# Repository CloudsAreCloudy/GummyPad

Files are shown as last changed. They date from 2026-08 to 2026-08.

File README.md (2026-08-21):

# GummyPad
An ESP32 C3 SuperMini Macropad with 12 Keys, an OLED Display, Rotary Encoder, and RGB LEDs!



## Bill of Materials (BOM)
| Part | Price (USD) | Quantity | Where to find it |
| ---- | ----- | --- | --- |
| M3x4mmx4.2mm Heat Set Brass Inserts | 0.45$ | 10 | [Purchase Here](https://quartzcomponents.com/products/m3-x-4mm-brass-heat-set-threaded-round-insert-nut-10-pcs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) |
| 100nF Capacitors | 0.32$ | 9 | [Purchase Here](https://quartzcomponents.com/products/100nf-0-1uf-50v-capacitor-0805-smd-pack-of-20-piece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) |
| SSD1306 0.96 Inch OLED Display | 1.51$ | 1 | [Purchase Here](https://quartzcomponents.com/products/oled-display-0-96-inch-i2c-interface-4-pin-blue-ssd1306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) |
| 3.7V 2000mAH Li-Po Battery | 2.58$ | 1 | [Purchase Here](https://quartzcomponents.com/products/3-7v-2000mah-li-po-rechargeable-battery-523450?variant=44853322449130) |
| TP4056 Charging Module | 0.17$ | 1 | [Purchase Here](https://quartzcomponents.com/products/tp4056-battery-charging-protection-module-type-c?variant=39545849774264) |
| 1N148 High-speed Diode | 0.38$ | 12 | [Purchase Here](https://quartzcomponents.com/products/1n4148-zener-diode?variant=42817413546218) |
| KY-040 Rotary Encoder | 0.49$ | 1 | [Purchase Here](https://quartzcomponents.com/products/rotary-encoder-module-ky-040?variant=39545890963640) |
| WS2821B 5050 LED Light | 0.94$ | 9 | [Purchase Here](https://probots.co.in/ws2812b-rgb-led-chip-5050-smd-white-addressable-intelligent.html) |
| M3 x 6mm Screws | 0.13$ | 10 | [Purchase Here](https://onlyscrews.in/products/m3-x-6mm-phillips-csk-ss-304-screw-dia-3mm-length-6mm?variant=52107976802617)
| M2.5 x 4mm Screws | 0.03$ | 2 | [Purchase Here](https://onlyscrews.in/products/m2-5-x-4mm-phillips-csk-ss-304-screw-dia-2-5mm-length-4mm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) |
| Keyboard Switches | 1.57$ | 12 | [Purchase Here](https://meckeys.com/shop/accessories/keyboard-accessories/key-switches/regular-switch-3pin/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) |
| ESP32-C3 Super Mini | 2.86$ | 1 | [Purchase Here](https://quartzcomponents.com/products/esp32-c3-super-mini-development-board-with-soldered-headers-hw-466ab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)
| PCB from JLCPCB | 2.18$ | 5 (MOQ) | [Purchase Here](JLCPCB.com) |
| 3D Printing (Self) | 0$ | 1 | NA |
| Shipping | 2.83$ | NA | NA |
| **Total** | 16.44$ | | |

## How can I build it?
 **Required Libraries:**
- ADAFRUIT_SSD1306
- KMK_Firmware

All you need to do is solder the Capacitors, Display, TP4056 Module, Battery, Diodes, Switches, Rotary Encoder, and LEDs onto the PCB, 3D Print the case and use a soldering iron to push the heat set inserts into place (M2.5 screws intentionally dont have heat set inserts), flash the ESP32-C3 Super Mini with CircuitPython, Load the code.py file into the root along with the KMK files and the specified libraries, and you should be good to go!




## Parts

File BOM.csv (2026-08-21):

Part | Price (USD) | Quantity | Where to find it
M3x4mmx4.2mm Heat Set Brass Inserts | 0.45$ | 10 | https://quartzcomponents.com/products/m3-x-4mm-brass-heat-set-threaded-round-insert-nut-10-pcs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
100nF Capacitors | 0.32$ | 9 | https://quartzcomponents.com/products/100nf-0-1uf-50v-capacitor-0805-smd-pack-of-20-piece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
SSD1306 0.96 Inch OLED Display | 1.51$ | 1 | https://quartzcomponents.com/products/oled-display-0-96-inch-i2c-interface-4-pin-blue-ssd1306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
3.7V 2000mAH Li-Po Battery | 2.58$ | 1 | https://quartzcomponents.com/products/3-7v-2000mah-li-po-rechargeable-battery-523450?variant=44853322449130
TP4056 Charging Module | 0.17$ | 1 | https://quartzcomponents.com/products/tp4056-battery-charging-protection-module-type-c?variant=39545849774264
1N148 High-speed Diode | 0.38$ | 12 | https://quartzcomponents.com/products/1n4148-zener-diode?variant=42817413546218
KY-040 Rotary Encoder | 0.49$ | 1 | https://quartzcomponents.com/products/rotary-encoder-module-ky-040?variant=39545890963640
WS2821B 5050 LED Light | 0.94$ | 9 | https://probots.co.in/ws2812b-rgb-led-chip-5050-smd-white-addressable-intelligent.html
M3 x 6mm Screws | 0.13$ | 10 | https://onlyscrews.in/products/m3-x-6mm-phillips-csk-ss-304-screw-dia-3mm-length-6mm?variant=52107976802617
M2.5 x 4mm Screws | 0.03$ | 2 | https://onlyscrews.in/products/m2-5-x-4mm-phillips-csk-ss-304-screw-dia-2-5mm-length-4mm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
Keyboard Switches | 1.57$ | 12 | https://meckeys.com/shop/accessories/keyboard-accessories/key-switches/regular-switch-3pin/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
ESP32-C3 Super Mini | 2.86$ | 1 | https://quartzcomponents.com/products/esp32-c3-super-mini-development-board-with-soldered-headers-hw-466ab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
PCB from JLCPCB | 2.18$ | 5 (MOQ) | jlcpcb.com
3D Printing (Self) | 0$ | 1 | NA
Shipping | 2.83$ | NA | NA
Total | 16.44$

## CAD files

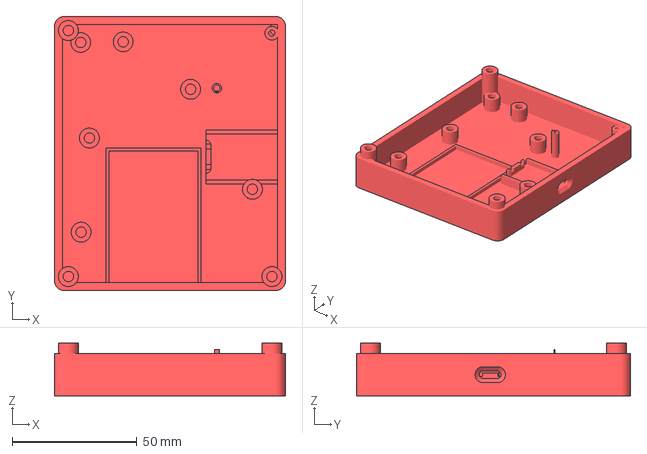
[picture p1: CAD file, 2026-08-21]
CAD/Case_Bottom.3mf
92.6 x 109.7 x 21.2 mm

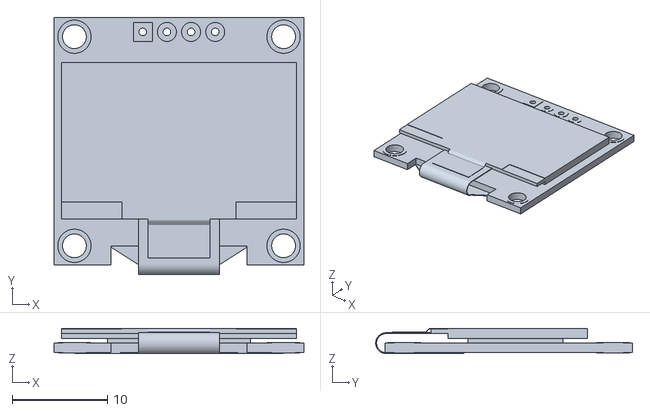
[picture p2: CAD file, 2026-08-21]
CAD/Components/Display_OLED_0.96_128x64.stl
26.3 x 27.0 x 2.65

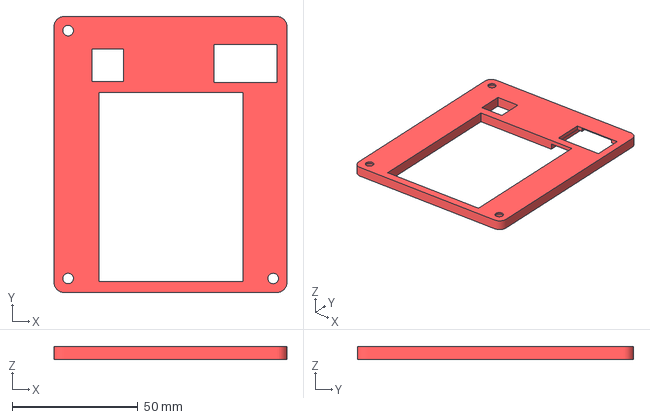
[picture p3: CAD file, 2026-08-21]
CAD/Case_Top.3mf
92.6 x 109.7 x 5.00 mm

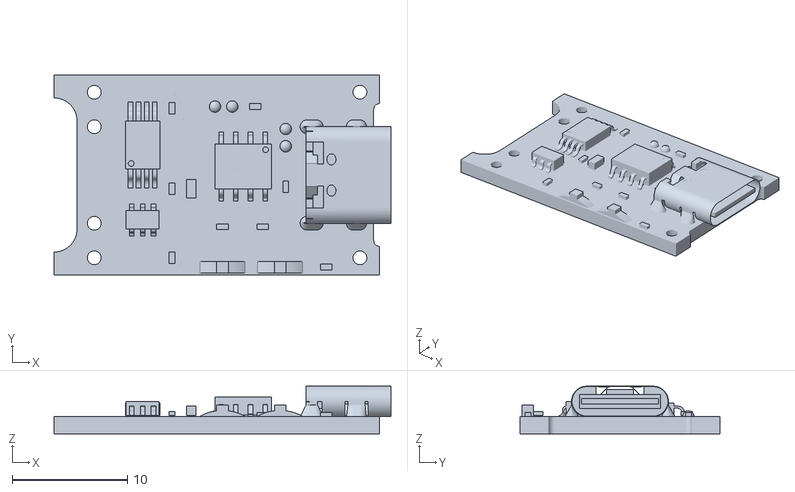
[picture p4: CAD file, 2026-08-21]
CAD/Components/TP4056_Charging_Module_Type_C.stl
29.3 x 17.4 x 4.14

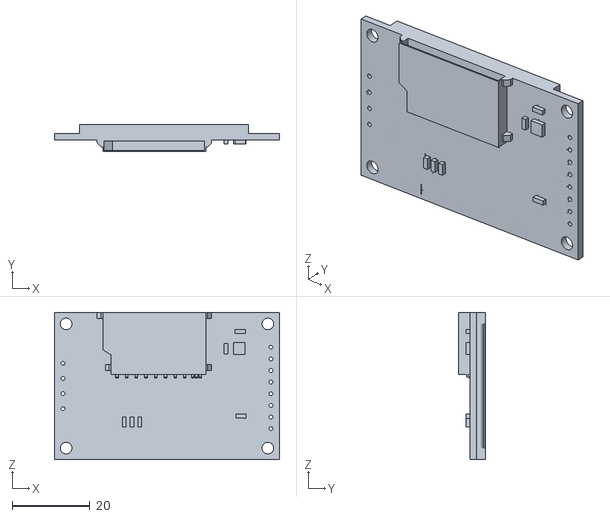
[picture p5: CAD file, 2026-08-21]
CAD/Components/LCD_TFT_1.8_SPI_ST7735.step.stl
58.0 x 7.00 x 38.0

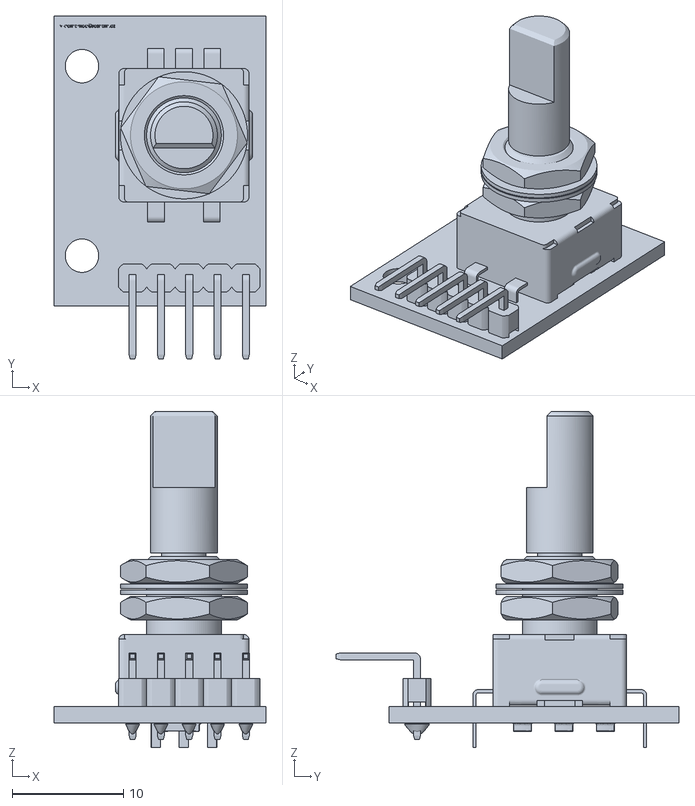
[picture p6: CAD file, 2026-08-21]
CAD/Components/KY-040.stl
19.0 x 30.8 x 30.2

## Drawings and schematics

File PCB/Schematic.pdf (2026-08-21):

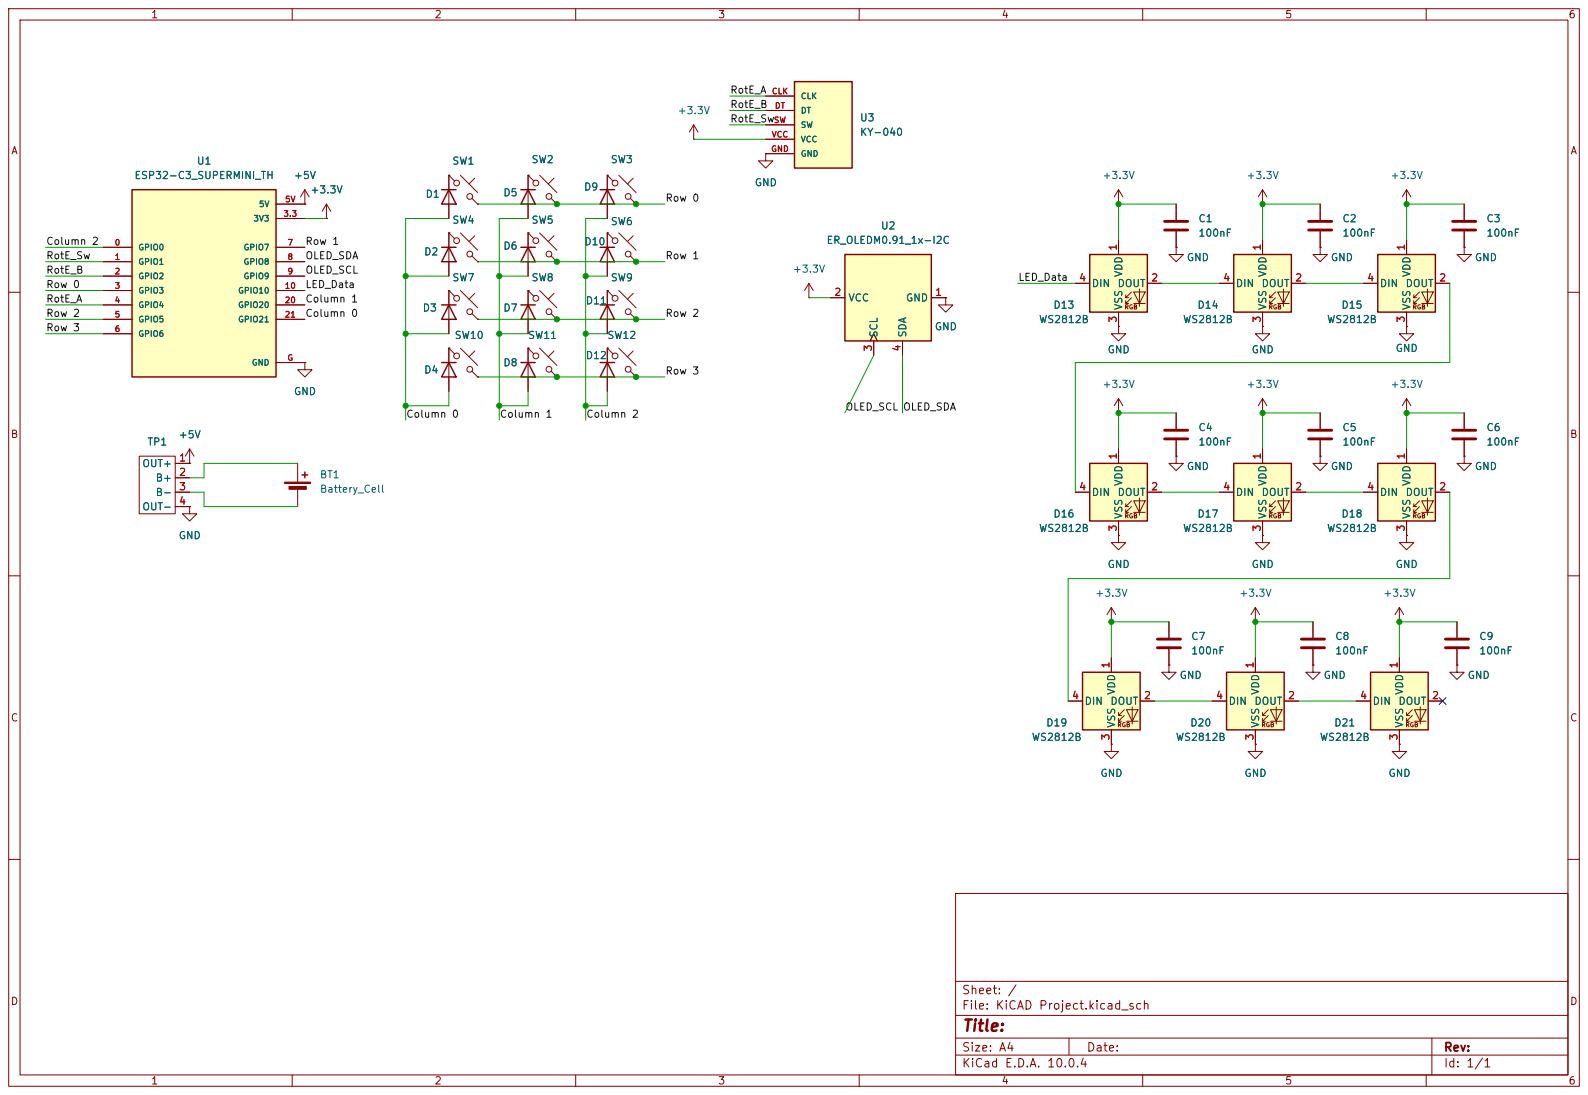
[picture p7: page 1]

LED_Data OLED_SDA OLED_SCL Column 0 Row 1 Row 2 Row 3 RotE_A RotE_B
Column 1 RotE_Sw

Size: A4 | Rev:
KiCad E.D.A. 10.0.4 | Id: 1/1

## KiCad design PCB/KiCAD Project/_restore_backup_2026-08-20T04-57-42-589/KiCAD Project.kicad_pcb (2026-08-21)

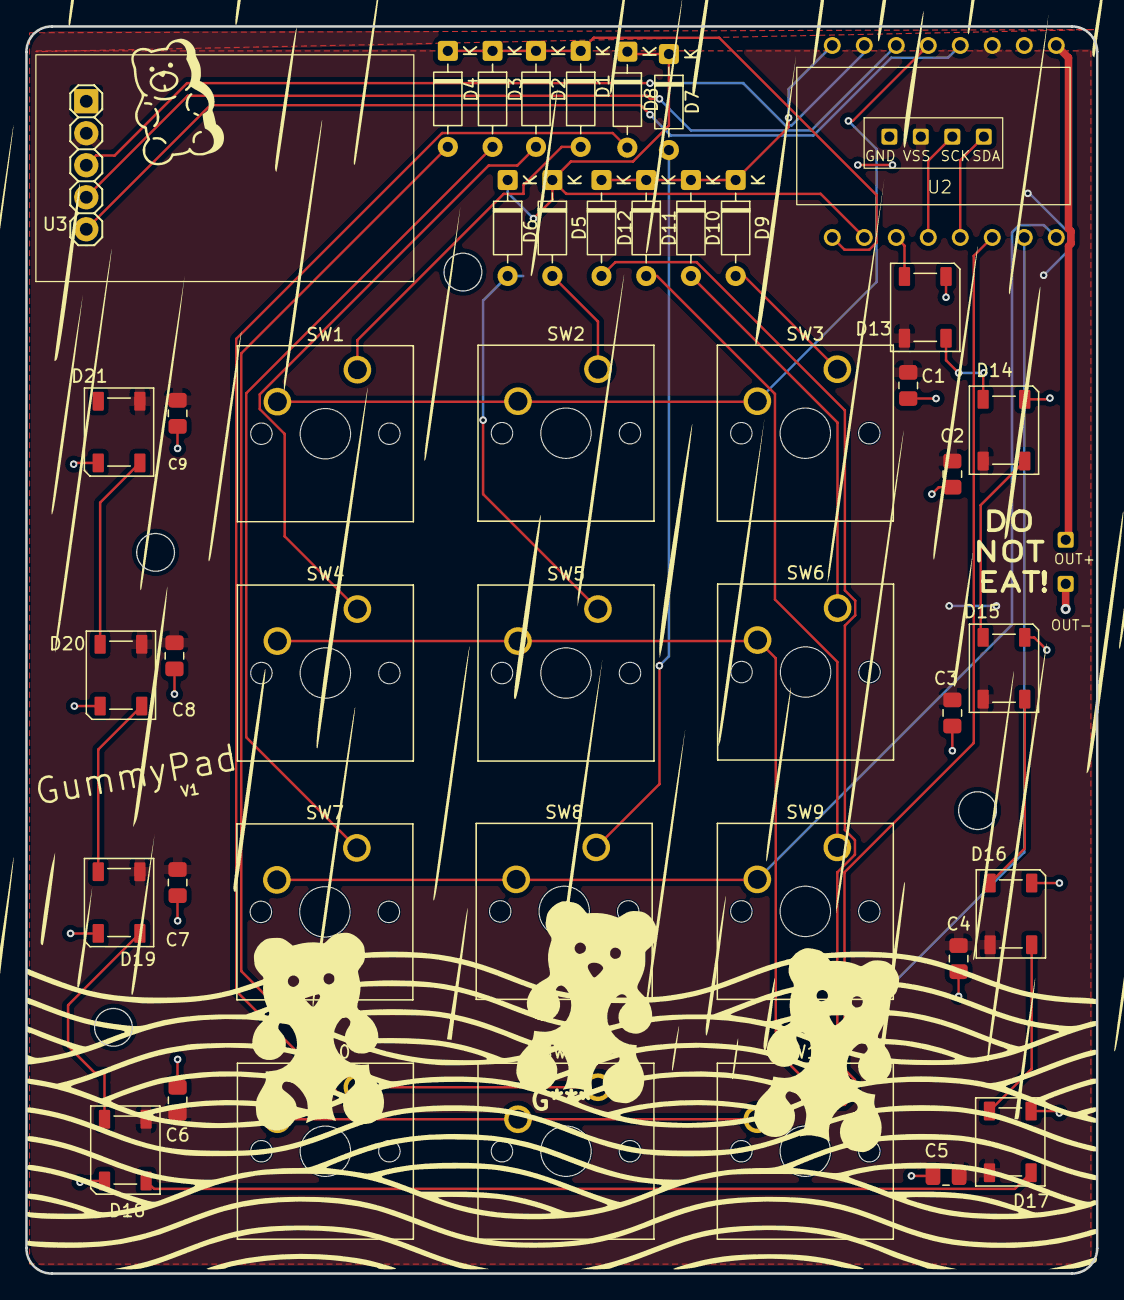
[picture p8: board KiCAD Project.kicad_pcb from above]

Board: 2 copper layers, 85.0 x 99.0 mm, 46 parts (1 on the bottom side), 36 nets.

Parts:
C1, C2, C3, C4, C5, C6, C7, C8, C9: 100nF; C_0805_2012Metric_Pad1.18x1.45mm_HandSolder
D1, D2, D3, D4, D5, D6, D7, D8, D9, D10, D11, D12: D_DO-35_SOD27_P7.62mm_Horizontal
D13, D14, D15, D16, D17, D18, D19, D20, D21: WS2812B; LED_WS2812B_PLCC4_5.0x5.0mm_P3.2mm
SW1, SW2, SW3, SW4, SW5, SW6, SW7, SW8, SW9, SW10, SW11, SW12: SW_Cherry_MX_1.00u_PCB
TP1: TP4056 Basic
U1: ESP32-C3_SUPERMINI_TH; MODULE_ESP32-C3_SUPERMINI_TH
U2: ER_OLEDM0.91_1x-I2C; I2C Display
U3: KY-040; KY-040-PORT

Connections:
+3.3V: C1.1, C2.1, C3.1, C4.1, C5.1, C6.1, C7.1, C8.1, C9.1, D13.1 (VDD), D14.1 (VDD), D15.1 (VDD), D16.1 (VDD), D17.1 (VDD), D18.1 (VDD), D19.1 (VDD), D20.1 (VDD), D21.1 (VDD), U1.3.3 (3V3), U2.2 (VCC), U3.VCC
+5V: TP1.1 (OUT+), U1.5V
/Column 0: D1.1 (K), D2.1 (K), D3.1 (K), D4.1 (K), U1.21 (GPIO21)
/Column 1: D5.1 (K), D6.1 (K), D7.1 (K), D8.1 (K), U1.20 (GPIO20)
/Column 2: D9.1 (K), D10.1 (K), D11.1 (K), D12.1 (K), U1.0 (GPIO0)
/LED_Data: D13.4 (DIN), U1.10 (GPIO10)
/OLED_SCL: U1.9 (GPIO9), U2.3 (SCL)
/OLED_SDA: U1.8 (GPIO8), U2.4 (SDA)
/RotE_A: U1.4 (GPIO4), U3.CLK
/RotE_B: U1.2 (GPIO2), U3.DT
/RotE_Sw: U1.1 (GPIO1), U3.SW
/Row 0: SW1.2, SW2.2, SW3.2, U1.3 (GPIO3)
/Row 1: SW4.2, SW5.2, SW6.2, U1.7 (GPIO7)
/Row 2: SW7.2, SW8.2, SW9.2, U1.5 (GPIO5)
/Row 3: SW10.2, SW11.2, SW12.2, U1.6 (GPIO6)
GND: C1.2, C2.2, C3.2, C4.2, C5.2, C6.2, C7.2, C8.2, C9.2, D13.3 (VSS), D14.3 (VSS), D15.3 (VSS), D16.3 (VSS), D17.3 (VSS), D18.3 (VSS), D19.3 (VSS), D20.3 (VSS), D21.3 (VSS), TP1.4 (OUT-), U1.G (GND), U2.1 (GND), U3.GND
unnamed: D1.2 (A), SW1.1
unnamed: D2.2 (A), SW4.1
unnamed: D3.2 (A), SW7.1
unnamed: D4.2 (A), SW10.1
unnamed: D5.2 (A), SW2.1
unnamed: D6.2 (A), SW5.1
unnamed: D7.2 (A), SW8.1
unnamed: D8.2 (A), SW11.1
unnamed: D9.2 (A), SW3.1
unnamed: D10.2 (A), SW6.1
unnamed: D11.2 (A), SW9.1
unnamed: D12.2 (A), SW12.1
unnamed: D13.2 (DOUT), D14.4 (DIN)
unnamed: D14.2 (DOUT), D15.4 (DIN)
unnamed: D15.2 (DOUT), D16.4 (DIN)
unnamed: D16.2 (DOUT), D17.4 (DIN)
unnamed: D17.2 (DOUT), D18.4 (DIN)
unnamed: D18.2 (DOUT), D19.4 (DIN)
unnamed: D19.2 (DOUT), D20.4 (DIN)
unnamed: D20.2 (DOUT), D21.4 (DIN)

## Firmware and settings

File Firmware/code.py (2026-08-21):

print("Starting...")

import board
import busio

from kmk.kmk_keyboard import KMKKeyboard
from kmk.keys import KC
from kmk.scanners import DiodeOrientation
from kmk.extensions.display import Display, TextEntry, ImageEntry
from kmk.extensions.display.ssd1306 import SSD1306
from kmk.extensions.RGB import RGB
from kmk.modules.layers import Layers
from kmk.modules.encoder import EncoderHandler

encoder_handler = EncoderHandler()
keyboard = KMKKeyboard()
layers = Layers()
i2c_bus = busio.I2C(board.GP9, board.GP8)
keyboard.modules = [layers, encoder_handler]
rgb = RGB(pixel_pin=board.GP10, num_pixels=9)


# Keyboard column and row configuration
keyboard.col_pins = (board.GP21, board.GP20, board.GP0)
keyboard.row_pins = (board.GP3, board.GP7, board.GP5, board.GP6)
keyboard.diode_orientation = DiodeOrientation.COL2ROW

# Rotary Encoder Configuration
encoder_handler.pins = (
    (board.GP4, board.GP2, board.GP1),
    )

encoder_handler.map = [ ((KC.VOLD, KC.VOLU, KC.MUTE),),
                        ]

# Display Configuration

driver = SSD1306(
    i2c=i2c_bus,
    device_address=0x3C,
    )

display = Display(
    display=driver,
    width=128,
    height=64,
    brightness=1,
    brightness_step=0.01,
    dim_time=25,
    dim_target=0.1,
    off_time=60,
    )
    

display.entries = [
    TextEntry(text="Hey Cloudy!", x=0, y=0)
    ]


keyboard.keymap = [
    [KC.A, KC.B, KC.C, KC.D, KC.E, KC.F, KC.G, KC.H, KC.I, KC.J, KC.K, KC.L] # Layer 1
    ]

if __name__ == '__main__':
    keyboard.extensions.append(display)
    keyboard.extensions.append(rgb)
    keyboard.go()

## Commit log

2026-08-21 Added PCB Files
    [KiCAD Project.kicad_pcb, KiCAD Project.kicad_sch, Macropad_Pick and Place.csv]
2026-08-21 Added CAD files
    [Case_Bottom.3mf, Case_Top.3mf, Display_OLED_0.96_128x64.stl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]
2026-08-21 Added Macropad Assembled CAD
2026-08-21 Added BOM to Readme
2026-08-21 Revise README with BOM updates and build instructions
    Updated the Bill of Materials with additional parts and prices, and added a section on how to build the GummyPad.
2026-08-21 Added schematic
